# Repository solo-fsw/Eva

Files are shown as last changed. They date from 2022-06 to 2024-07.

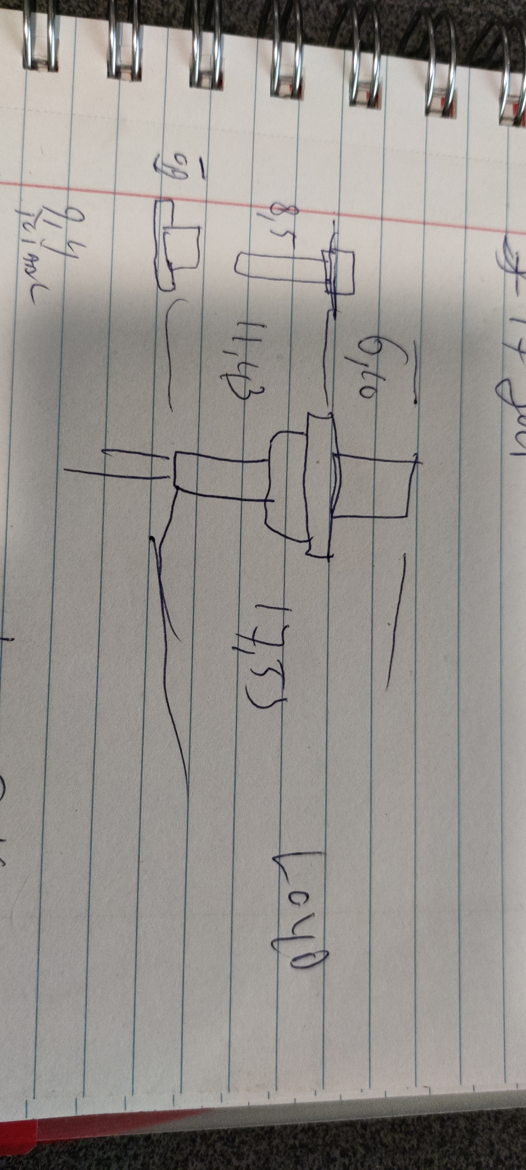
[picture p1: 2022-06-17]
Hardware/Parts/IMG_20200903_204815.jpg

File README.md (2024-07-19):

# Eva
Eva is a replacement of PST's SRBox (Serial Response Box) and the parallel port (LPT). It is used for sending or receiving markers. It also processes button responses, which are interpreted as keyboard buttons 1 - 8.

## Response Buttons
Responses from the response buttons are interpreted as keyboard events.
Button1 corresponds to keyboard 1, Button2 to keyboard 2 etc.
There are only events on button presses, not button releases.
Button markers for Biosemi are D8 for Button1, D9 for Button2 etc.
| Button | Keyboard event	| Biosemi marker |
| --- | --- | --- |
| 1 |	1	| D8 |
| 2	| 2	| D9 |
| 3	| 3	| D10 |
| 4	| 4	| D11 |
| 5	| 5	| D12 |
| 6	| 6	| D13 |
| 7	| 7	| D14 |
| 8	| 8	| D15 |

## Passive/Active data mode
Eva can operate in passive or active data mode.
The main difference is that in active data mode the Biopac connector is **output** for markers. In passive data mode the Biopac connector is **input**.
Active data mode is the normal operation mode, that is used most of the time.

***Active data Mode:***
All markers received over the serial usb port will be set on the Biosemi and Biopac connector.
Eva will set the value off the switches S0-S7 on the Biosemi and Biopac connector when pressing the Trigger button.

***Passive data mode:***
This mode can be handy when you still want to use the parallel port as marker source. The parallel port cable need to be connected to the Biopac connector. Received markers will be send to the Biosemi connector and will be shown on led D0-D7. 
Received markers on serial usb port and markers generated with the S0-S7 will be ignored.
Passive mode will be indicated by the passive red led.

## Switch between passive and active data mode
There are 3 possible options to switch between the active and passive data mode.
- Hold down the trigger button during powering up the Eva, the data mode will be toggled and comfirmed by the led Passive.
- Place Eva in command mode and send an S for passive data mode or A for active data mode.
- When the box detects during boot an high level on bit2 (0x04) it will switch to passive data mode.  

Most parallel ports output bit2 high before initializing, if Eva detects this it’s most likely connected to an parallel port and will switch to input to protect itself.  
Passive mode will be indicated by the passive red led.

## Data and command mode
Data mode is used for sending markers, all the data that is sent over the serial usb connection will be set on the output connectors Biosemi and Biopac.
To put the Eva in data mode open the comport @ 115200 baud, 8 bits, none parity, 1 stop bit (115200,8,N,1).

For switching to command mode open the comport @ 4800 baud (4800,8,N,1).
The red led Cmd will light up when it is in command mode.
 
## Command mode commands
- V - Gives info about Eva. Response is a Json String: *{"Version":"HW1:SW1.2","Serialno":"S01234","Device":"Eva"}*
- S - Puts Eva in passive data mode. Response: *Passive*
- A - Puts Eva in active data mode
- M - Returns the current state of the data mode. Response: *Active*
- P - Pings Eva to see if it’s alive. Response: *Pong,Eva*

Other commands will be ignored. Response: *Unknown command* 

Commands are case sensitive.

## How to use
- In Python, the [marker_management library](https://github.com/solo-fsw/python-markers) can be used. 
- In OpenSesame, the [markers_os4 plugin](https://github.com/solo-fsw/opensesame4_plugin_markers) (for OpenSesame 4) or [markers_os3 plugin](https://github.com/solo-fsw/opensesame3_plugin_markers) (for OpenSesame 3) can be used. 
- In E-Prime, the [Markers package](https://github.com/solo-fsw/eprime_package_markers) can be used.
- In MATLAB, see the [UsbParMarker documentation](https://github.com/solo-fsw/UsbParMarker/tree/main#matlab).

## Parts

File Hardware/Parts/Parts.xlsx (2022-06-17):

Count | Part | Part# | Supplier | Supplier# | Datasheet | Notes
24 | Light Pipe | LFB037CTP | Digikey | LFB037CTP-ND | http://static.vcclite.com/pdf/LFBSeries.pdf
24 | Led Green | APTD2012LZGCK | Digikey | 754-2048-1-ND | http://www.kingbrightusa.com/images/catalog/SPEC/APTD2012LZGCK.pdf
2 | D25 | 5745187-1 | Digikey | A34049-ND | https://www.te.com/commerce/DocumentDelivery/DDEController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
~~1~~ | ~~Behuizing~~ | ~~Hammond 1599EGY~~ | ~~Rs~~ | ~~207-2114~~ | ~~https://docs.rs-online.com/8845/0900766b814a5012.pdf~~
4 | Schroef D25 | UNC 4-40 Screwlock | Rs | 453-886 | https://docs.rs-online.com/521a/0900766b8158246d.pdf
1 | Behuizing | Hammond 1591HGY | Rs | 493-6206 | https://www.hammfg.com/files/parts/pdf/1591HGY.pdf
2 | Led red | APTD2012LSURCK | Digikey | 754-2044-1-ND | https://www.kingbrightusa.com/images/catalog/SPEC/APTD2012LSURCK.pdf
8 | Bnc | R141426161 | Rs | 721-0291 | https://docs.rs-online.com/a538/0900766b80f1f98b.pdf
3 | Stand off |  | Rs-components | 184-2160 | https://nl.rs-online.com/web/p/standoffs/1842160/
~~3~~ | ~~Bout stand off~~ |  | ~~Rvs-paleis~~ |  | ~~https://www.rvspaleis.nl/bouten/torx/ws-9475/ws-9475-[-]-a2-[-]-m2,5/9475-2-2.5x4_100~~
4 | Bout Lid |  | Rvs-paleis |  | https://www.rvspaleis.nl/bouten/torx/ws-9475/ws-9475-[-]-a2-[-]-m3/9475-2-3x5_100
3 | Bout onder stand off |  | Rvs-paleis |  | https://www.rvspaleis.nl/bouten/torx/din-7985tx/din-7985tx-[-]-a2-[-]-m2,5/7985-2-2.5x5tx_100

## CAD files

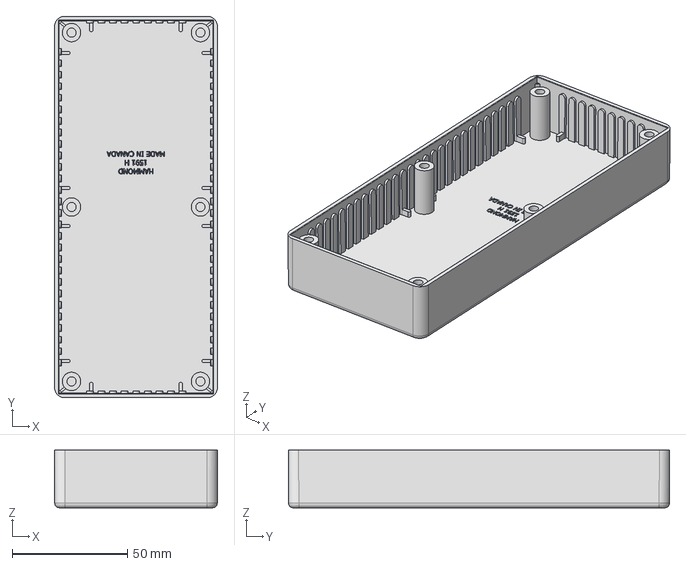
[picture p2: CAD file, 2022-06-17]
Hardware/Parts/DataSheet/Behuizing/1591H Box.stp
70.8 x 165.7 x 25.0 mm

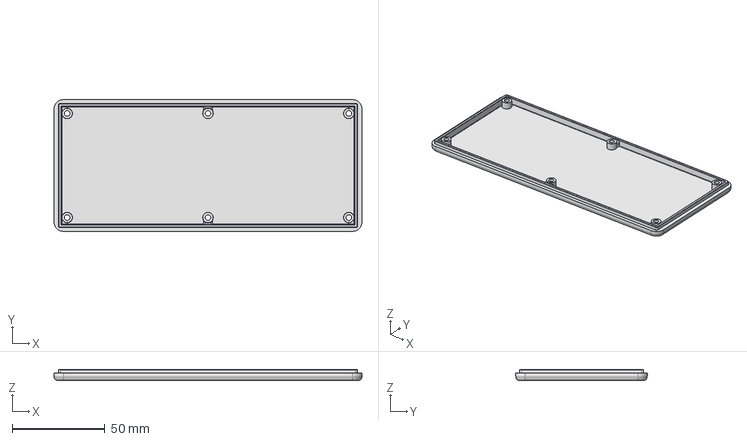
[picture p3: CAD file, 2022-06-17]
Hardware/Parts/DataSheet/Behuizing/1591H Lid.stp
165.7 x 70.8 x 6.00 mm

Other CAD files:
Hardware/Parts/DataSheet/Behuizing/1591H.dwg
Hardware/Parts/DataSheet/Behuizing/1591H Box.igs
Hardware/Parts/DataSheet/Behuizing/1591H Lid.igs

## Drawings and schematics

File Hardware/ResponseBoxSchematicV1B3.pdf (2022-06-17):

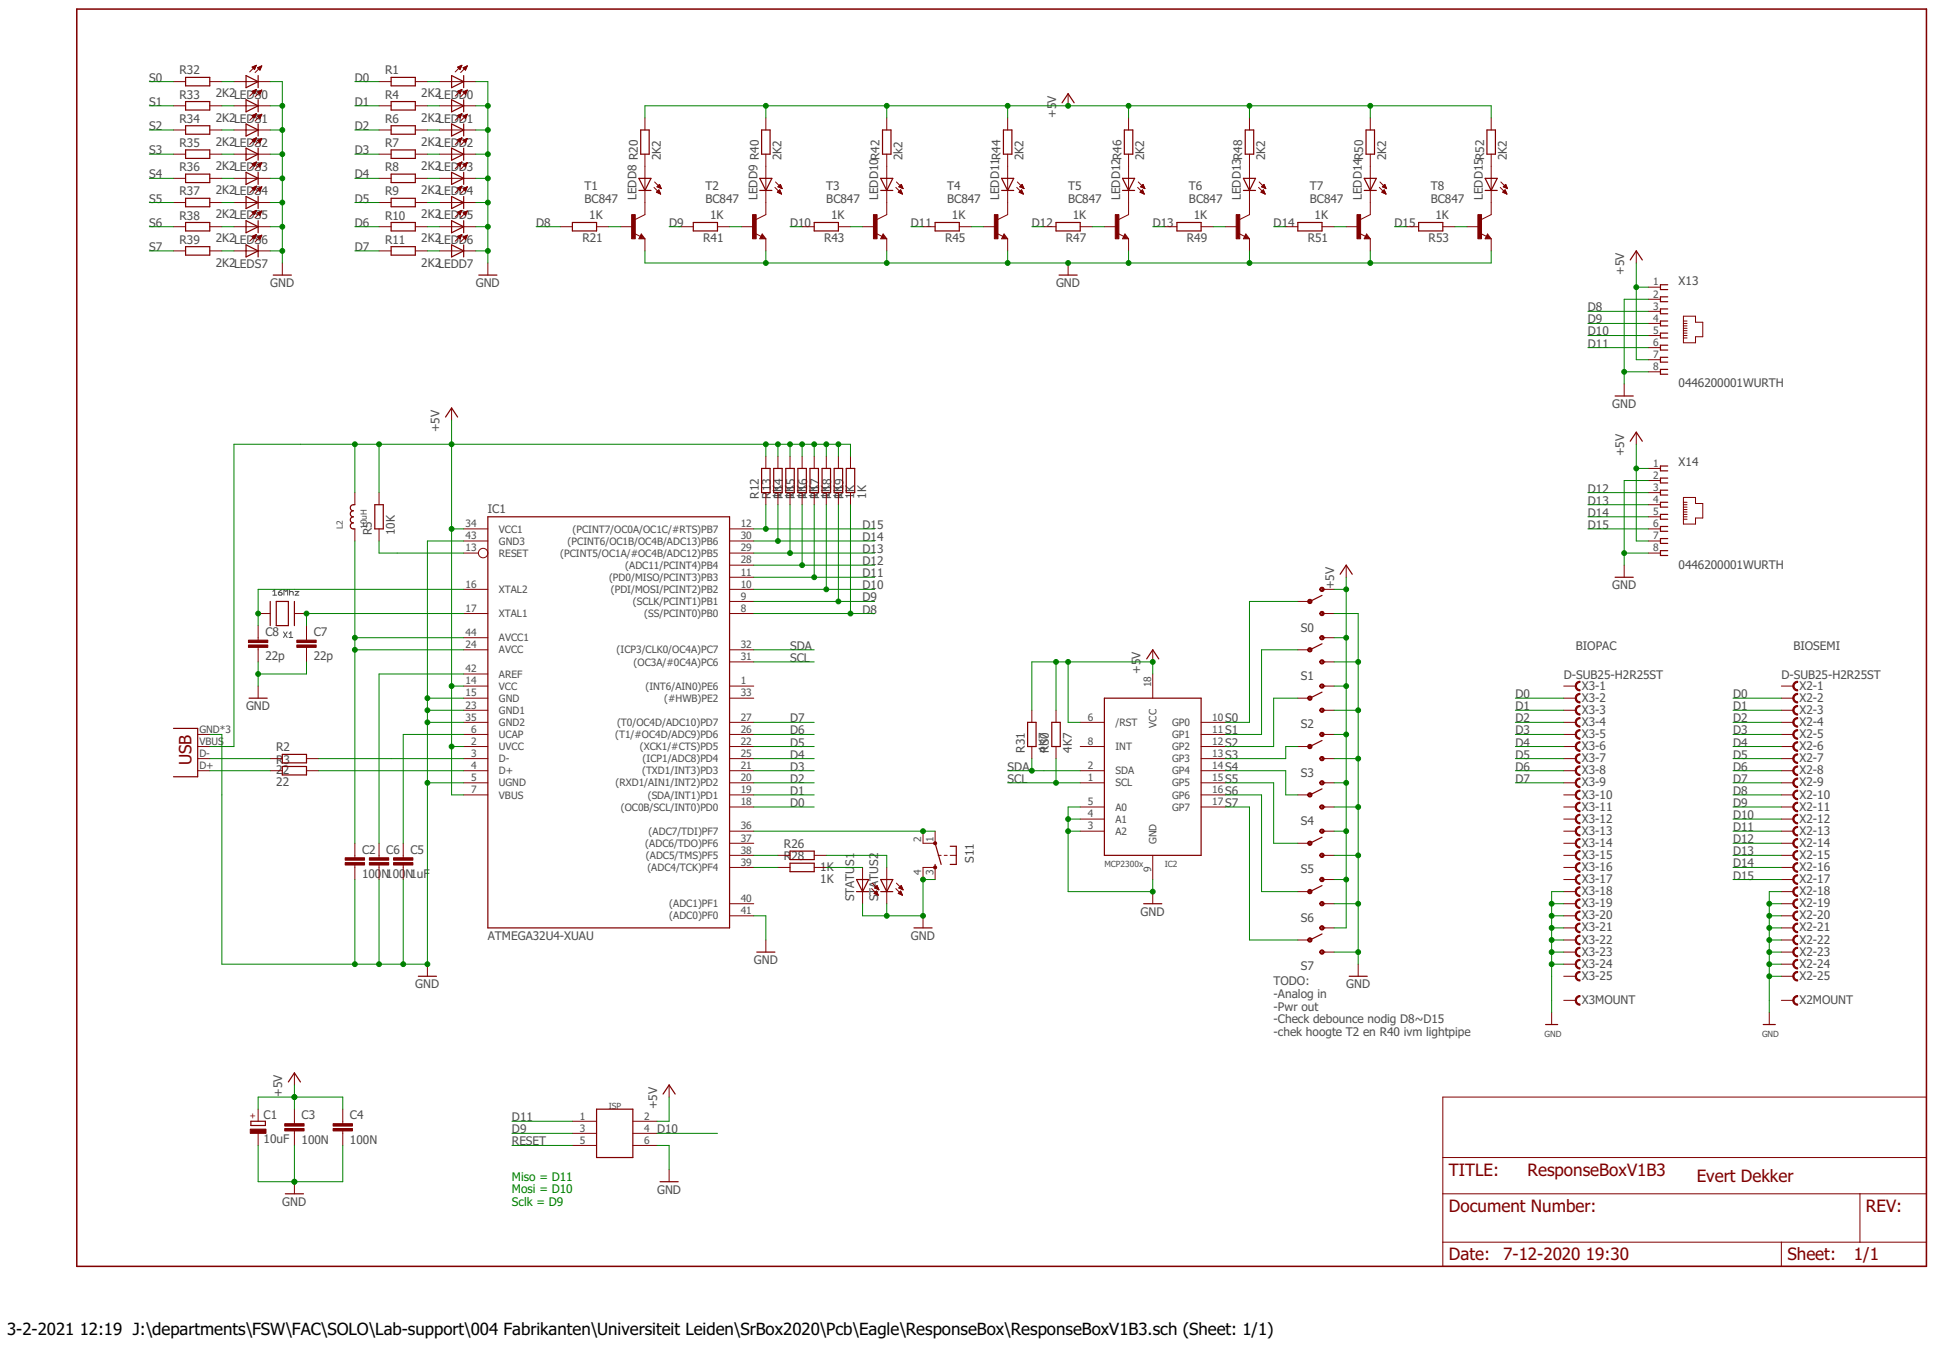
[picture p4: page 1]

28 | D12
11 | D11
10 | D10

14
15 | 33

-Pwr out -Check debounce nodig D8~D15

-chek hoogte T2 en R40 ivm lightpipe

Document Number: | REV:

Date: 7-12-2020 19:30 | Sheet: 1/1

3-2-2021 12:19 J:\departments\FSW\FAC\SOLO\Lab-support\004 Fabrikanten\Universiteit Leiden\SrBox2020\Pcb\Eagle\ResponseBox\ResponseBoxV1B3.sch (Sheet: 1/1)

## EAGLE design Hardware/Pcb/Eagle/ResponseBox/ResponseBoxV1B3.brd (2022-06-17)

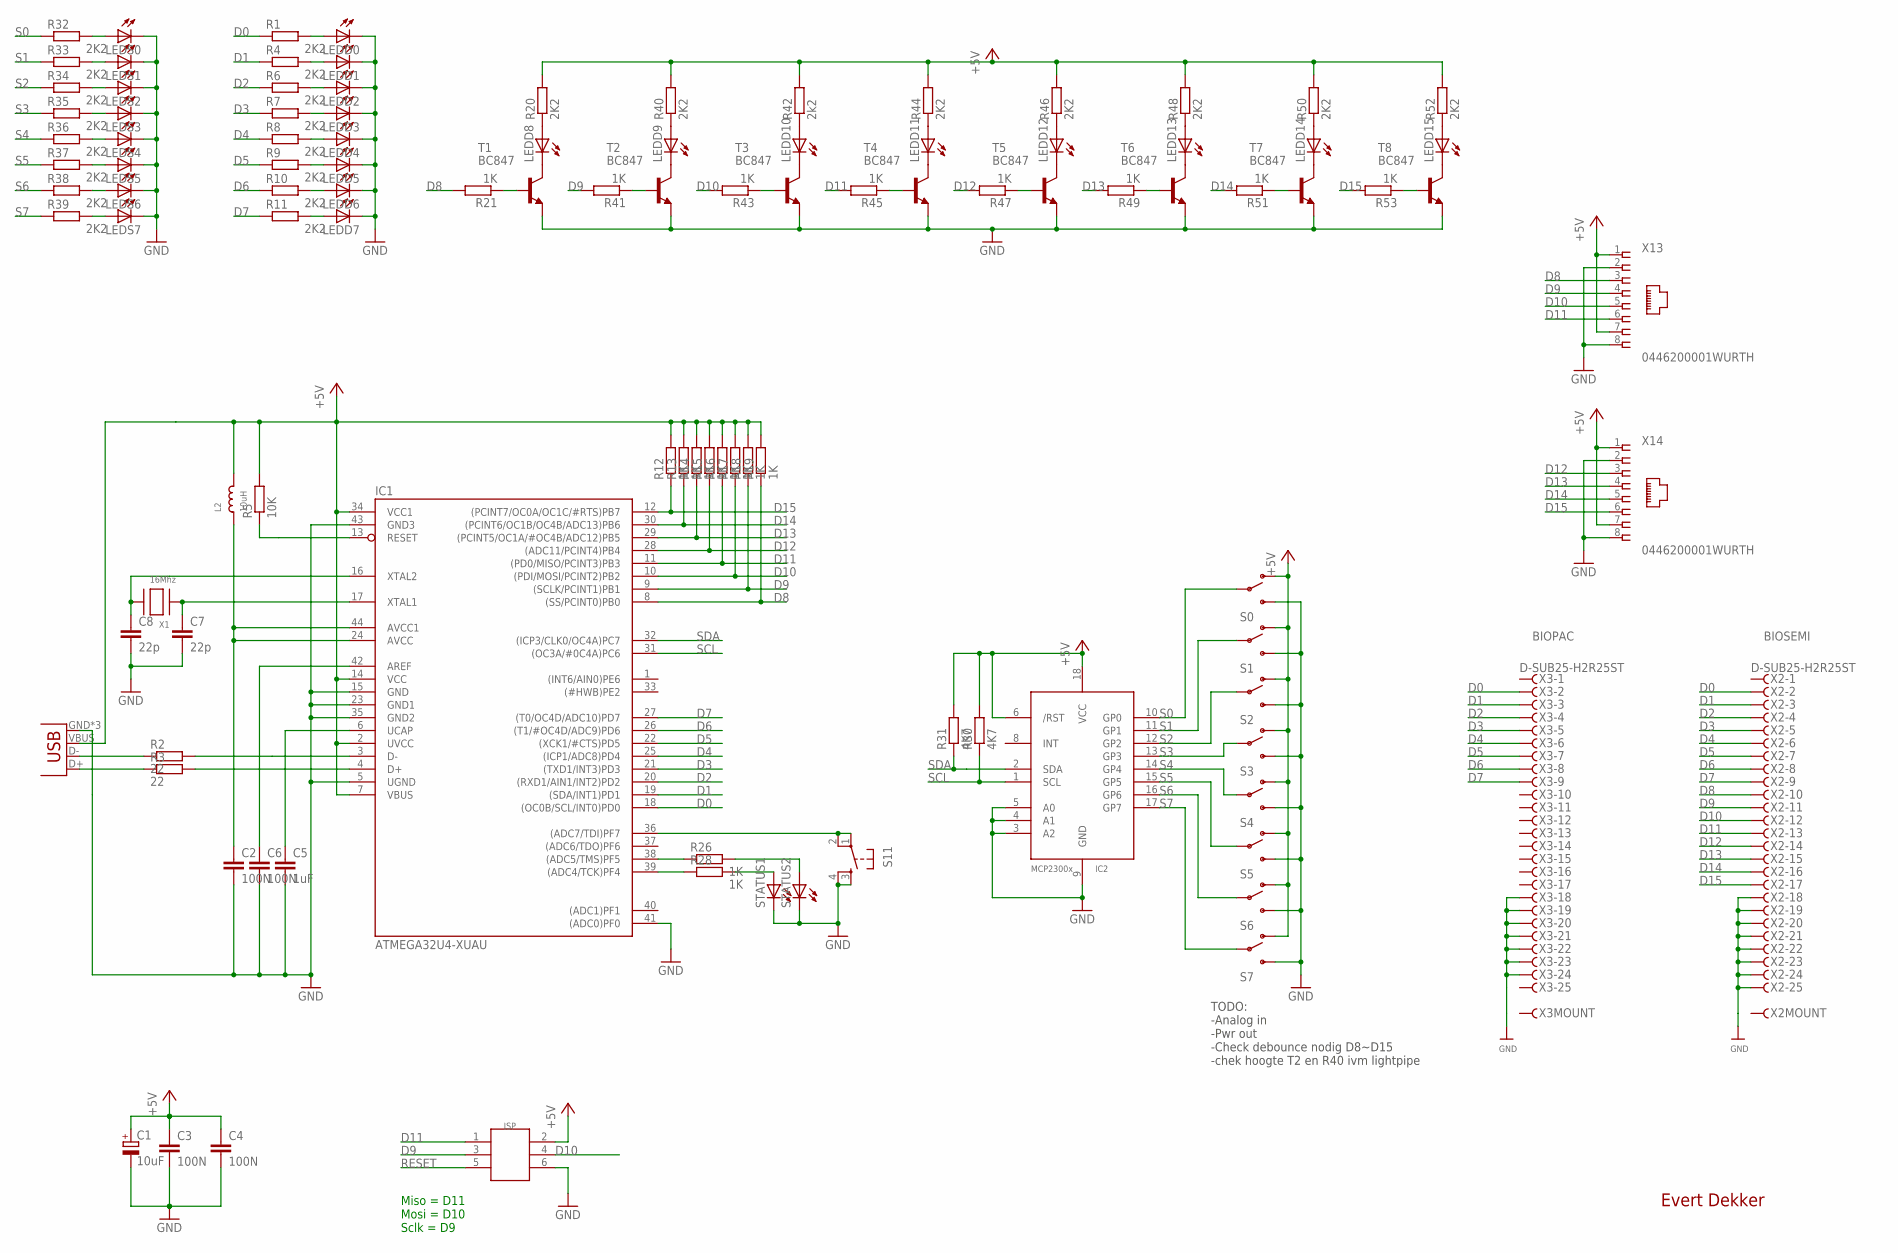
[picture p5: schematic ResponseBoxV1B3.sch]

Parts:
C1: 10uF; R/2012-12R; FARNELL 1867958
C2, C3: 100N; C0805; FARNELL 1833888
C4, C6: 100N; C0805
C5: 1uF; C0805; FARNELL 1327700
C7, C8: 22p; C0805; FARNELL 1759489
IC1: ATMEGA32U4-XUAU; TQFP44-PAD; FARNELL 1748525
IC2: MCP2300X/SO; SO18W; FARNELL 1332086
ISP: HEADER-2X3P-SMD; 2X3P-2.54-SMD; FARNELL 9689567
L2: 10uH; 0805; FARNELL 2215650
LEDD0, LEDD1, LEDD8, LEDD9, LEDD10, LEDD11, LEDD12, LEDD13, LEDD14, LEDD15: LEDCHIPLED_0805; CHIPLED_0805
LEDD2, LEDD3, LEDD4, LEDD5, LEDD6: LEDCHIP-LED0805; CHIP-LED0805
LEDD7: LEDCHIP-LED0805; CHIP-LED0805; FARNELL 2062573
LEDS0: LEDCHIPLED_0805; CHIPLED_0805; FARNELL 2062573
LEDS1: LEDCHIPLED_0805; CHIPLED_0805
LEDS2, LEDS3, LEDS4, LEDS5, LEDS6, LEDS7: LEDCHIP-LED0805; CHIP-LED0805
R1, R32: 2K2; R0805; FARNELL 2447686
R2: 22; R0805; FARNELL 2447609
R3: 22; R0805
R4, R6, R7, R8, R9, R10, R11, R20, R33, R34, R35, R36, R37, R38, R39, R40, R44, R46, R48, R50, R52: 2K2; R0805
R5: 10K; R0805; FARNELL 2447553
R12: 1K; R0805; FARNELL 2074332
R13, R14, R15, R16, R17, R18, R19, R21, R26, R28, R41, R43, R45, R47, R49, R51, R53: 1K; R0805
R30: 4K7; R0805; FARNELL 2694141
R31: 4K7; R0805
R42: 2k2; R0805
S0: SWITCH-SPST; SPDT-2MS; FARNELL 9472967
S1, S2, S3, S4, S5, S6, S7: SWITCH-SPST; SPDT-2MS
S11: 10-XX3ESMD; 3ESMD
STATUS1, STATUS2: LEDCHIP-LED0805; CHIP-LED0805
T1: BC847; SOT23; FARNELL 1081230
T2, T3, T4, T5, T6, T7, T8: BC847; SOT23
X1: 16Mhz; NX5032; FARNELL 2467791
X2, X3: D-SUB25-H2R25ST; H2R25ST; FARNELL 2752229
X12: USBPTH-VERTICAL; USB-B-PTH-VERTICAL; FARNELL 1696538
X13, X14: 0446200001WURTH; WURTH-WR-MJ; FARNELL 1841170

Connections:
+5V: C1.+, C3.2, C4.2, IC1.2 (UVCC), IC1.7 (VBUS), IC1.14 (VCC), IC1.34 (VCC1), IC2.6 (/RST), IC2.18 (VCC), ISP.2, L2.2, R5.2, R12.2, R13.2, R14.2, R15.2, R16.2, R17.2, R18.2, R19.2, R20.2, R30.2, R31.2, R40.2, R42.2, R44.2, R46.2, R48.2, R50.2, R52.2, S0.1 (O), S1.1 (O), S2.1 (O), S3.1 (O), S4.1 (O), S5.1 (O), S6.1 (O), S7.1 (O), X12.VBUS, X13.1, X13.7, X14.1, X14.7
D0: IC1.18 ((OC0B/SCL/INT0)PD0), R1.1, X2.2, X3.2
D1: IC1.19 ((SDA/INT1)PD1), R4.1, X2.3, X3.3
D2: IC1.20 ((RXD1/AIN1/INT2)PD2), R6.1, X2.4, X3.4
D3: IC1.21 ((TXD1/INT3)PD3), R7.1, X2.5, X3.5
D4: IC1.25 ((ICP1/ADC8)PD4), R8.1, X2.6, X3.6
D5: IC1.22 ((XCK1/#CTS)PD5), R9.1, X2.7, X3.7
D6: IC1.26 ((T1/#OC4D/ADC9)PD6), R10.1, X2.8, X3.8
D7: IC1.27 ((T0/OC4D/ADC10)PD7), R11.1, X2.9, X3.9
D8: IC1.8 ((SS/PCINT0)PB0), R19.1, R21.2, X2.10, X13.3
D9: IC1.9 ((SCLK/PCINT1)PB1), ISP.3, R18.1, R41.2, X2.11, X13.4
D10: IC1.10 ((PDI/MOSI/PCINT2)PB2), ISP.4, R17.1, R43.2, X2.12, X13.5
D11: IC1.11 ((PD0/MISO/PCINT3)PB3), ISP.1, R16.1, R45.2, X2.13, X13.6
D12: IC1.28 ((ADC11/PCINT4)PB4), R15.1, R47.2, X2.14, X14.3
D13: IC1.29 ((PCINT5/OC1A/#OC4B/ADC12)PB5), R14.1, R49.2, X2.15, X14.4
D14: IC1.30 ((PCINT6/OC1B/OC4B/ADC13)PB6), R13.1, R51.2, X2.16, X14.5
D15: IC1.12 ((PCINT7/OC0A/OC1C/#RTS)PB7), R12.1, R53.2, X2.17, X14.6
D+: IC1.4 (D+), R3.2
D-: IC1.3 (D-), R2.2
GND: C1.-, C2.2, C3.1, C4.1, C5.2, C6.2, C7.2, C8.2, IC1.5 (UGND), IC1.15 (GND), IC1.23 (GND1), IC1.35 (GND2), IC1.41 ((ADC0)PF0), IC1.43 (GND3), IC2.3 (A2), IC2.4 (A1), IC2.5 (A0), IC2.9 (GND), ISP.6, LEDD0.C, LEDD1.C, LEDD2.C, LEDD3.C, LEDD4.C, LEDD5.C, LEDD6.C, LEDD7.C, LEDS0.C, LEDS1.C, LEDS2.C, LEDS3.C, LEDS4.C, LEDS5.C, LEDS6.C, LEDS7.C, S0.3 (S), S1.3 (S), S2.3 (S), S3.3 (S), S4.3 (S), S5.3 (S), S6.3 (S), S7.3 (S), S11.3 (S), S11.4 (S1), STATUS1.C, STATUS2.C, T1.2 (E), T2.2 (E), T3.2 (E), T4.2 (E), T5.2 (E), T6.2 (E), T7.2 (E), T8.2 (E), X2.18, X2.19, X2.20, X2.21, X2.22, X2.23, X2.24, X2.25, X3.18, X3.19, X3.20, X3.21, X3.22, X3.23, X3.24, X12.GND, X12.MP1 (GND), X12.MP2 (GND), X13.2, X13.8, X14.2, X14.8
unnamed: R2.1, X12.D-
unnamed: R3.1, X12.D+
unnamed: LEDD8.A, R20.1
unnamed: LEDD8.C, T1.3 (C)
unnamed: R21.1, T1.1 (B)
unnamed: C2.1, IC1.24 (AVCC), IC1.44 (AVCC1), L2.1
unnamed: LEDD0.A, R1.2
unnamed: LEDD1.A, R4.2
unnamed: IC1.38 ((ADC5/TMS)PF5), R26.1
unnamed: IC1.39 ((ADC4/TCK)PF4), R28.1
unnamed: R26.2, STATUS2.A
unnamed: R28.2, STATUS1.A
unnamed: LEDD2.A, R6.2
unnamed: LEDD3.A, R7.2
unnamed: LEDD4.A, R8.2
unnamed: LEDD5.A, R9.2
unnamed: LEDD6.A, R10.2
unnamed: LEDD7.A, R11.2
unnamed: LEDS0.A, R32.2
unnamed: LEDS1.A, R33.2
unnamed: LEDS2.A, R34.2
unnamed: LEDS3.A, R35.2
unnamed: LEDS4.A, R36.2
unnamed: LEDS5.A, R37.2
unnamed: LEDS6.A, R38.2
unnamed: LEDS7.A, R39.2
unnamed: IC1.36 ((ADC7/TDI)PF7), S11.1, S11.2 (P1)
unnamed: LEDD9.A, R40.1
unnamed: LEDD9.C, T2.3 (C)
unnamed: R41.1, T2.1 (B)
unnamed: LEDD10.A, R42.1
unnamed: LEDD10.C, T3.3 (C)
unnamed: R43.1, T3.1 (B)
unnamed: C6.1, IC1.42 (AREF)
unnamed: C5.1, IC1.6 (UCAP)
unnamed: LEDD11.A, R44.1
unnamed: LEDD11.C, T4.3 (C)
unnamed: R45.1, T4.1 (B)
unnamed: LEDD12.A, R46.1
unnamed: LEDD12.C, T5.3 (C)
unnamed: R47.1, T5.1 (B)
unnamed: LEDD13.A, R48.1
unnamed: LEDD13.C, T6.3 (C)
unnamed: R49.1, T6.1 (B)
unnamed: LEDD14.A, R50.1
unnamed: LEDD14.C, T7.3 (C)
unnamed: R51.1, T7.1 (B)
unnamed: LEDD15.A, R52.1
unnamed: LEDD15.C, T8.3 (C)
unnamed: R53.1, T8.1 (B)
RESET: IC1.13 (RESET), ISP.5, R5.1
S0: IC2.10 (GP0), R32.1, S0.2
S1: IC2.11 (GP1), R33.1, S1.2
S2: IC2.12 (GP2), R34.1, S2.2
S3: IC2.13 (GP3), R35.1, S3.2
S4: IC2.14 (GP4), R36.1, S4.2
S5: IC2.15 (GP5), R37.1, S5.2
S6: IC2.16 (GP6), R38.1, S6.2
S7: IC2.17 (GP7), R39.1, S7.2
SCL: IC1.31 ((OC3A/#0C4A)PC6), IC2.1 (SCL), R30.1
SDA: IC1.32 ((ICP3/CLK0/OC4A)PC7), IC2.2 (SDA), R31.1
XTAL1: C7.1, IC1.17 (XTAL1), X1.P$1
XTAL2: C8.1, IC1.16 (XTAL2), X1.P$2

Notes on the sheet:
Evert Dekker
TODO: -Analog in -Pwr out -Check debounce nodig D8~D15 -chek hoogte T2 en R40 ivm lightpipe
BIOPAC
BIOSEMI
Miso = D11 Mosi = D10 Sclk = D9

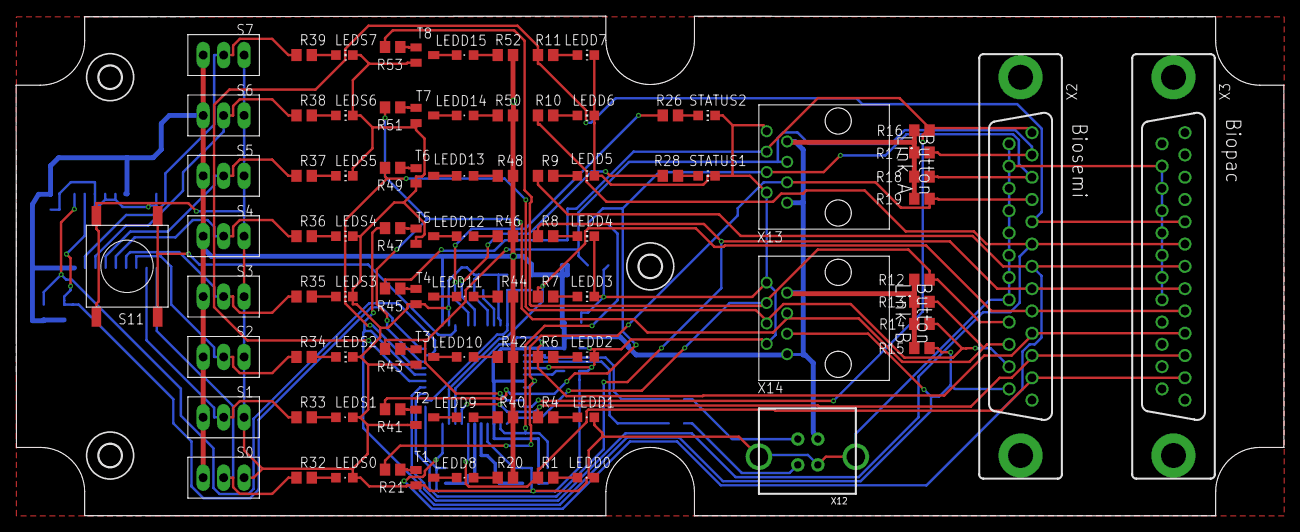
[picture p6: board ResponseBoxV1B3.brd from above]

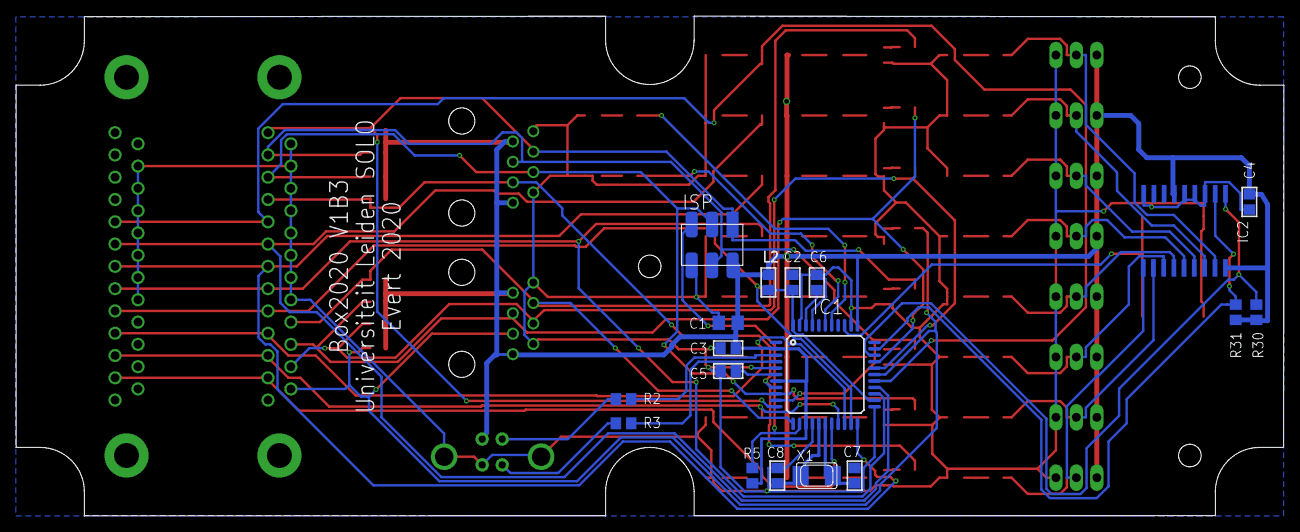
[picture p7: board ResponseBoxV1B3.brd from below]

Board: 2 copper layers, 157.5 x 62.1 mm, 111 parts (18 on the bottom side), 83 nets.

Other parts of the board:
U$2, U$4, U$6: MOUNTINGHOLE_2.8

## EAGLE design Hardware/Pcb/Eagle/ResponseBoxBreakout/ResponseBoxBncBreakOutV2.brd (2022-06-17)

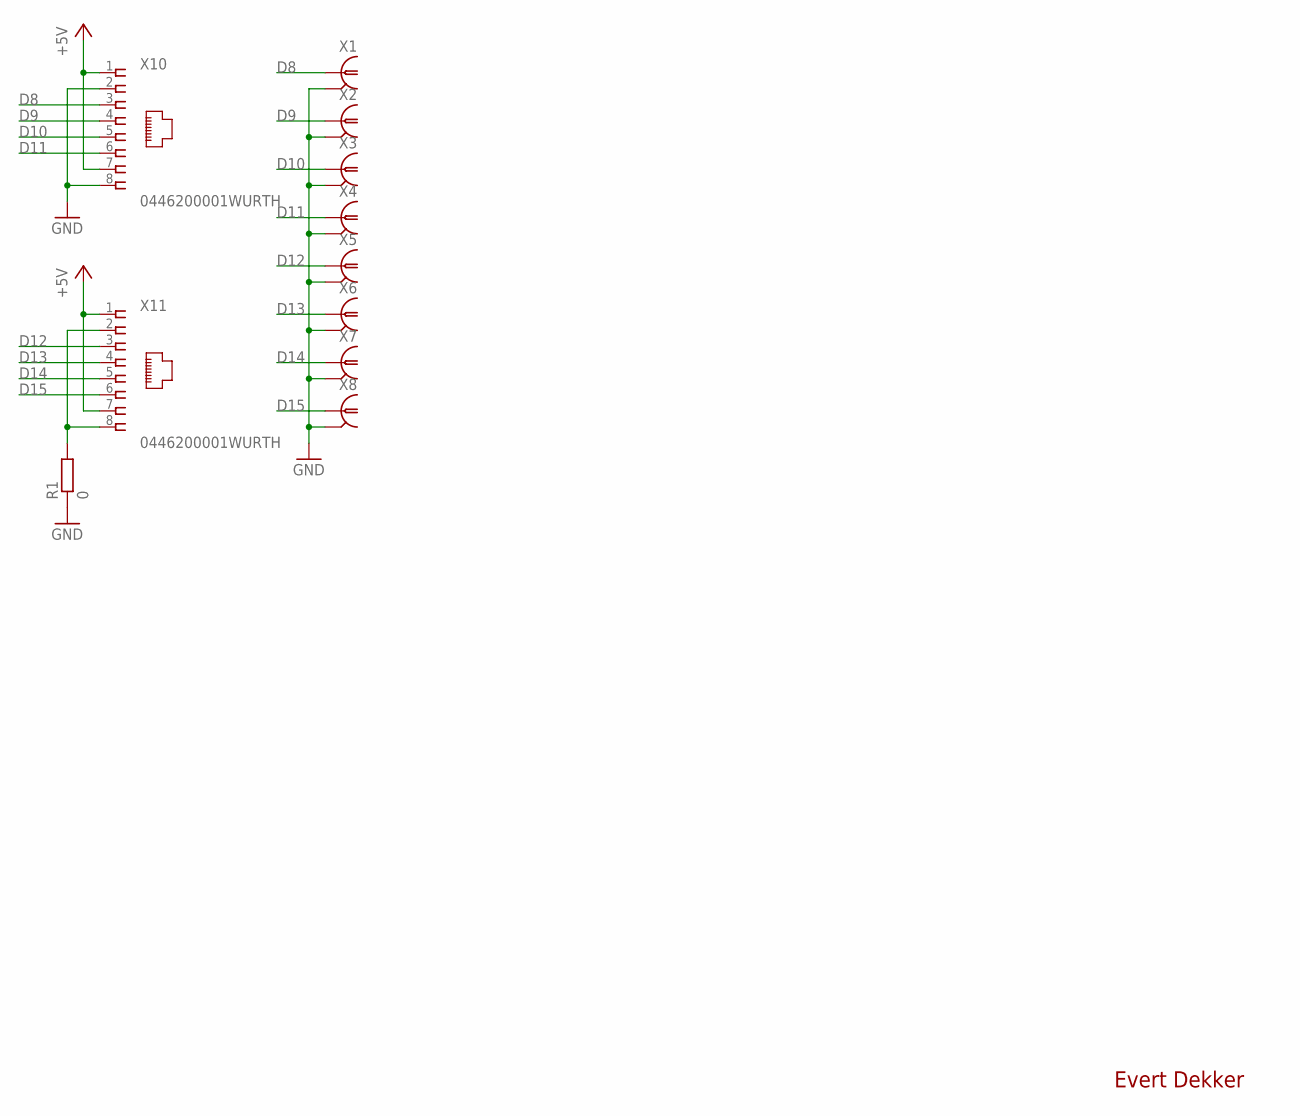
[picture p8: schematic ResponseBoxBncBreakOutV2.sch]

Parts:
R1: 0; M0805
X1, X2, X3, X4, X5, X6, X7, X8: R141426
X10, X11: 0446200001WURTH; WURTH-WR-MJ; FARNELL 1841170

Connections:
+5V: X10.1, X10.7, X11.1, X11.7
D8: X1.1, X10.3
D9: X2.1, X10.4
D10: X3.1, X10.5
D11: X4.1, X10.6
D12: X5.1, X11.3
D13: X6.1, X11.4
D14: X7.1, X11.5
D15: X8.1, X11.6
GND: R1.1, X1.2, X1.3 (2), X1.4 (2), X1.5 (2), X2.2, X2.3 (2), X2.4 (2), X2.5 (2), X3.2, X3.3 (2), X3.4 (2), X3.5 (2), X4.2, X4.3 (2), X4.4 (2), X4.5 (2), X5.2, X5.3 (2), X5.4 (2), X5.5 (2), X6.2, X6.3 (2), X6.4 (2), X6.5 (2), X7.2, X7.3 (2), X7.4 (2), X7.5 (2), X8.2, X8.3 (2), X8.4 (2), X8.5 (2), X10.2, X10.8
unnamed: R1.2, X11.2, X11.8

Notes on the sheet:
Evert Dekker

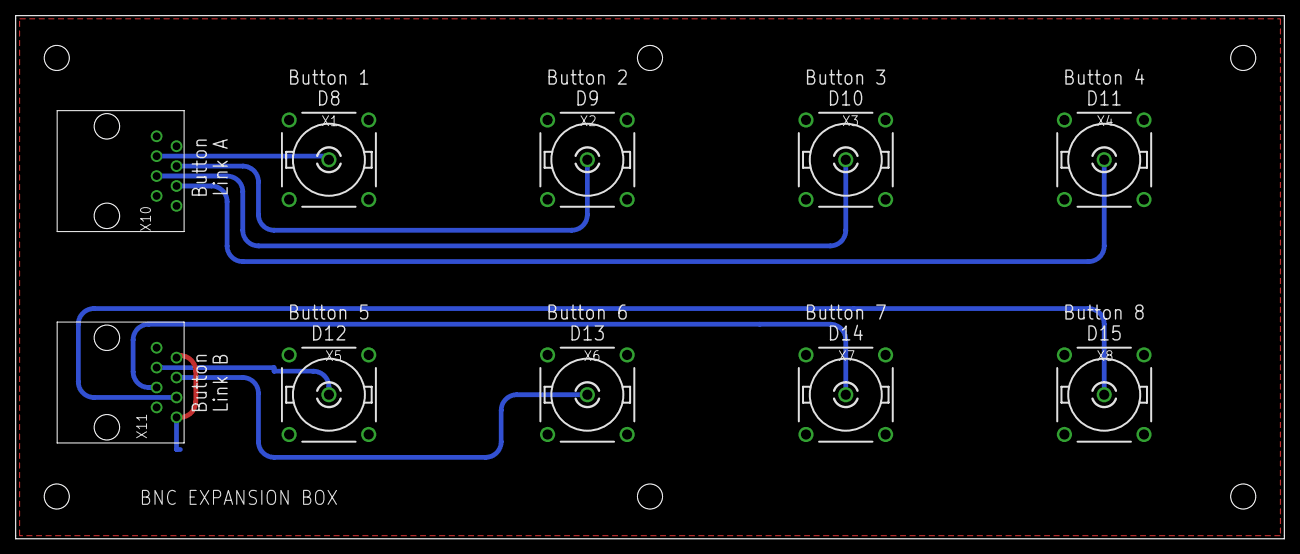
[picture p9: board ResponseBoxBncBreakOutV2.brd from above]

Board: 2 copper layers, 162.0 x 66.8 mm, 11 parts (1 on the bottom side), 11 nets.

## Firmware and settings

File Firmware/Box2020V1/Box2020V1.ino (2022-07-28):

#include "Box2020V1.h"



#undef TX_RX_LED_INIT  //DDRD |= (1<<5), DDRB |= (1<<0)
#undef TXLED0    //  PORTD |= (1<<5)
#undef TXLED1    //  PORTD &= ~(1<<5)
#undef RXLED0    //  PORTB |= (1<<0)
#undef RXLED1    //  PORTB &= ~(1<<0)

void setup() {
  lptconnected();           //Check if lpt cable from pc is connected to the Biopac (or Biosemi) connector
  //writeStringToEEPROM(10,"S00794");
  Serialno = readStringFromEEPROM(10);

  pinMode(STATUSLED1, OUTPUT);
  pinMode(STATUSLED2, OUTPUT);
  Serial.begin(115200);     // opens serial port, sets data rate to 115200 bps
  changemode();  //check if button is pressed during boot to change mode
  button.setCallback(buttonChanged);  //callback switch for marker sending
  DDRB = 0x00;           //PortB all pins input, Buttons
  i2cinit();
  Keyboard.begin();
}

void loop() {
  button.update();                  //scan Trigger button
  if (Serial.baud() == 115200) {    //data mode
    if (Serial.available() > 0) {
      PORTD = Serial.read();       //send marker to output port
    }
    digitalWrite(STATUSLED2, LOW);
  }
  else if (Serial.baud() == 4800) { //command mode
    digitalWrite(STATUSLED2, HIGH);
    if (Serial.available() > 0) {
      handlecommands();
    }
  }
  debounceRespButtons();
}

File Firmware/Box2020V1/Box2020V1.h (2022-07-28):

/* IMPORTANT NOTE
  TXLED must be disabled to prevent Interference with PORTD, done with #UNDEF
*/

/* IMPORTANT NOTE
  TXLED must be disabled to prevent Interference with the COL6, todo this change these 5 lines in the Arduino ..\variants\leonardo\pins_arduino.h file
  #define TX_RX_LED_INIT  //DDRD |= (1<<5), DDRB |= (1<<0)
  #define TXLED0    //  PORTD |= (1<<5)
  #define TXLED1    //  PORTD &= ~(1<<5)
  #define RXLED0    //  PORTB |= (1<<0)
  #define RXLED1    //  PORTB &= ~(1<<0)
*/

//20210501	1.0	Initial release
//20220211 	1.1 Changed DumpInfo to output Jsonstring
//20220617  1.2 Changed name Srbox2020 to Eva
//20220728  1.3 Responsebuton where responding slow after opening and closing the com port. This due some leftover Serial.write for debug purpose in debounceRespButtons()

//Hardware macros
#define BUTTON   A0    //PF7    *defines can be found in arduino\hardware\arduino\avr\variants\leonardo\pins_arduino.h* 
#define SDA_PORT PORTC   //C7
#define SDA_PIN 7
#define SCL_PORT PORTC  //C6
#define SCL_PIN 6
#define STATUSLED2 A3  //F4
#define STATUSLED1 A2  //F5

#define I2C_TIMEOUT 100
#define I2C_FASTMODE 1

#define STX 0x02 //start of text
#define ETX 0x03 //end of text
#define PING 81


#include <ButtonDebounce.h>
#include <SoftWire.h>  //Needs to be place below the i2c port defines
#include <avr/io.h>  //required for SoftWire
#include <EEPROM.h>
#include <Keyboard.h>

//Instance
ButtonDebounce button(BUTTON, 10);
SoftWire Wire = SoftWire();

//Globals
byte mode;
byte lastrespbutton =0;
unsigned long lastDebounceTime = 0;  // the last time the output pin was toggled
unsigned long debounceDelay = 1; //was 10 
byte lastFlickerableState = 0;
const String Version = "HW1:SW1.3";
const String Serialno;

//Enums
enum mode {
  ACTIVE,
  PASSIVE
};

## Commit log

2022-07-28 Bug fix slow buttons
    Responsebuton where responding slow after opening and closing the com port. This due some leftover Serial.write for debug purpose in debounceRespButtons()
    [Box2020V1.h, Box2020V1.ino, buttons.ino]
2022-08-05 Adjusted sample tasks
    Eva_Sample_Task:
    - Includes all package calls
    - Includes use of task events for sending markers
    - Includes instructions
    Eva_Sample_noPackage:
    - All package calls are included as func/sub in script
    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
2022-09-02 Added OpenSesame sample for sending markers to EVA and minor adjustments Python module
2023-02-28 added info about sample to readme
2023-06-27 removed samples

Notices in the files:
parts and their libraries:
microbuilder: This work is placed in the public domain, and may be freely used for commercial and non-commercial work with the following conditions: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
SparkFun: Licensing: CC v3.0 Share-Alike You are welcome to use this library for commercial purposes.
